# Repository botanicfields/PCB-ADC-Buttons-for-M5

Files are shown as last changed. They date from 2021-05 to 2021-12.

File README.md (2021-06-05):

# PCB-ADC-Button-for-M5
a PCB converts 5 buttons into 1 analog output

# M5 用光センサ・押しボタン 5 基板
## Ambient Light Sensor and 5 Buttons for M5

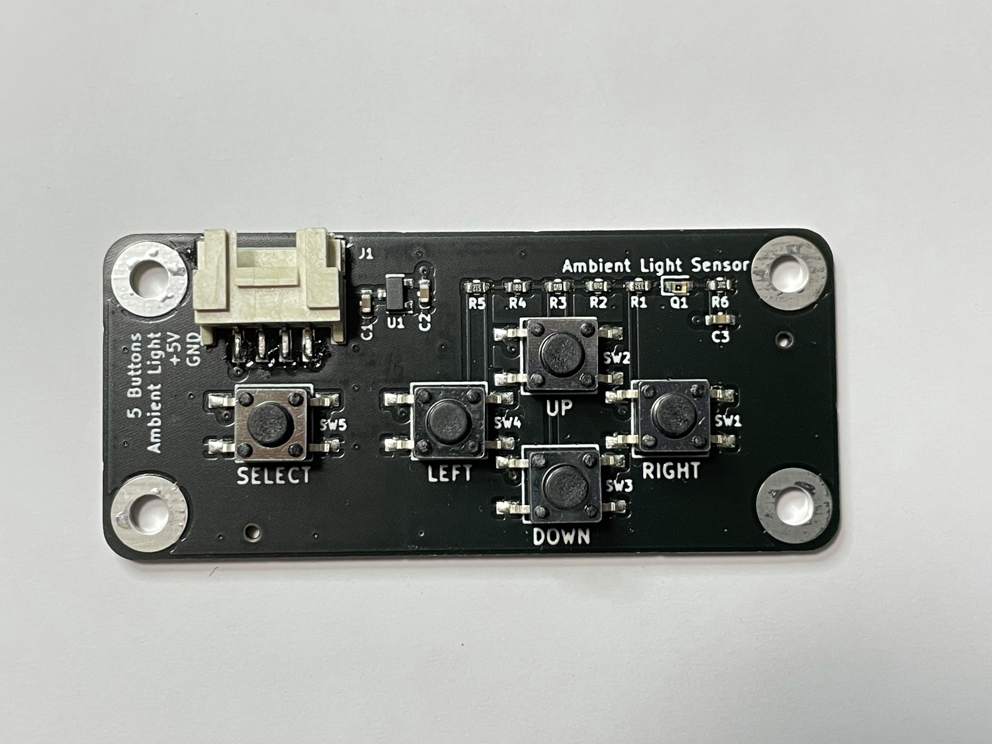
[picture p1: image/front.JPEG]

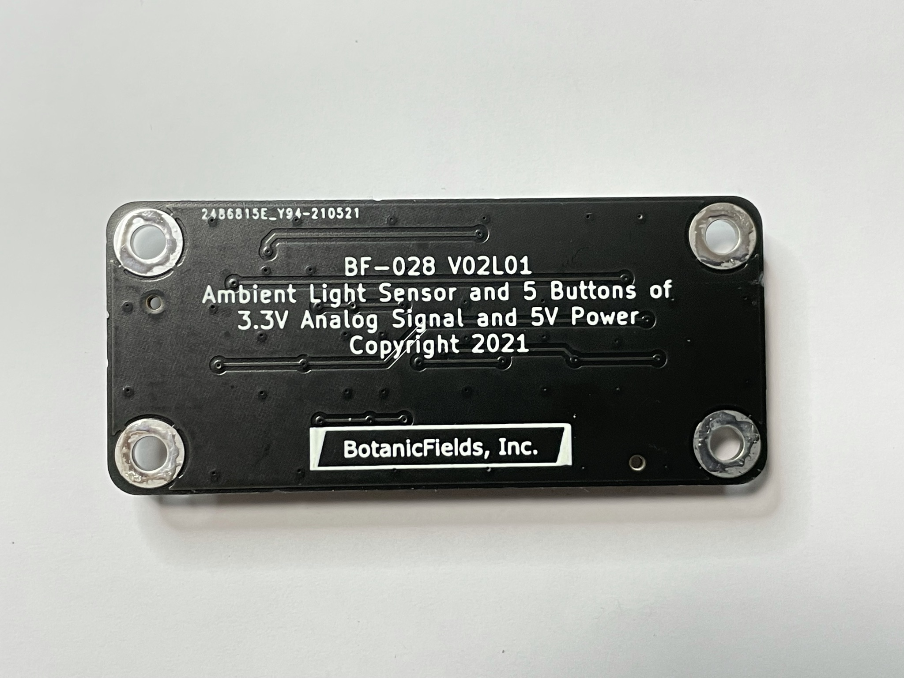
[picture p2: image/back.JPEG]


### 委託販売: スイッチサイエンス

https://www.switch-science.com/catalog/7227/

# 1. 特徴

- 周囲の明るさをアナログ電圧で出力します
- 押しボタン 5 個の操作を、1 本のアナログ電圧で出力します
- GROVE コネクタで接続します
- 出力レベルは 0 ~ 3.3V で、M5(ESP32) の GPIO に合わせています
- 電源は 5V で、M5シリーズの GROVE コネクタに合わせています
- JC_Button と同等の判定を可能とするプログラムを用意しています
- 手に持つことを考慮し、スルーホール部品を使用していません
- センサーへの影響を考慮し、パイロットランプはありません。

# 2. 注意
- 押しボタンスイッチのチャタリングや接触抵抗による誤動作が皆無とは言えません。時刻の設定など、結果を確認しながら操作し、やり直しを可能とするなど、運用でカバーできる範囲でご利用ください。

- 複数ボタンの同時押しの判定はできません。

- M5Stack Basic の GROVE コネクタに直結して使用することはできません。
「GROVE-ジャンパケーブル」などを用いて、アナログ入力の GPIO および 5V, GND に接続する必要があります。

「GROVE - 4ピン - ジャンパオスケーブル（5本セット）」

https://www.switch-science.com/catalog/6245/)

「GROVE - 4ピン-ジャンパメスケーブル (5本セット)」

https://www.switch-science.com/catalog/1048/

M5Stack Basic で、G35, G36, 5V, GND に接続した例

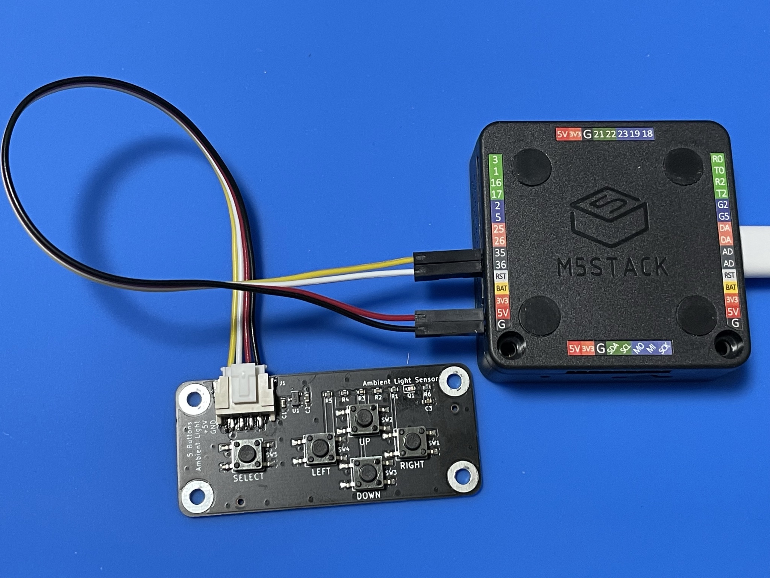
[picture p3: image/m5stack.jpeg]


## M5 シリーズの GROVE ポート

　M5 シリーズ (ESP32) では、アナログ入力として一般に G32 ～ G39 が使用されます。
G2, G4, G12 ~ G15, G24 ~ G26 のアナログ入力機能は、Wi-Fi 等が使用しますので
一般には使いづらいです。G0 はプルアップがあるなどアナログ入力には向きません。

| モデル | GROVE | 主な用途 |
|:-:|:-:|:-:|
| M5Stack Basic| G22, G21 | I2C |
| M5Stack Core2| G33, G32 | I2C, I/O, UART |
| M5StickC | G33, G32 | I2C, I/O, UART |
| M5Atom | G32, G26 | I2C, I/O, UART |

# 3. 内容

## 光センサ
Everlight ALS-PT19

https://jp.everlight.com/wp-content/plugins/ItemRelationship/product_files/pdf/ALS-PT19-315C-L177-TR8_V8.pdf

## ソフトウェア

### (1) BF_AdcButton.h, BF_Adc_Button.cpp
光センサの出力を読み出すプログラム、および 5 個の押しボタンの状態を読み出すプログラムです。JC_Button を流用・改変しています。

https://github.com/JChristensen/JC_Button

### (2) BF_AdcButtonTest.h, BF_Adc_ButtonTest.cpp
上記コードを呼び出すテスト用のプログラムです。

### (3) BF-028.ino
上記テストプログラムのメインプログラムです。

# 4. 解説
Qiita 「ESP32 のアナログ入力で、押しボタン 5 個を判別する」

https://qiita.com/BotanicFields/items/15d8d45836a4d2f6c87a

# 5. 接続例
「RGB LED 276 for M5Atom」への接続例です。

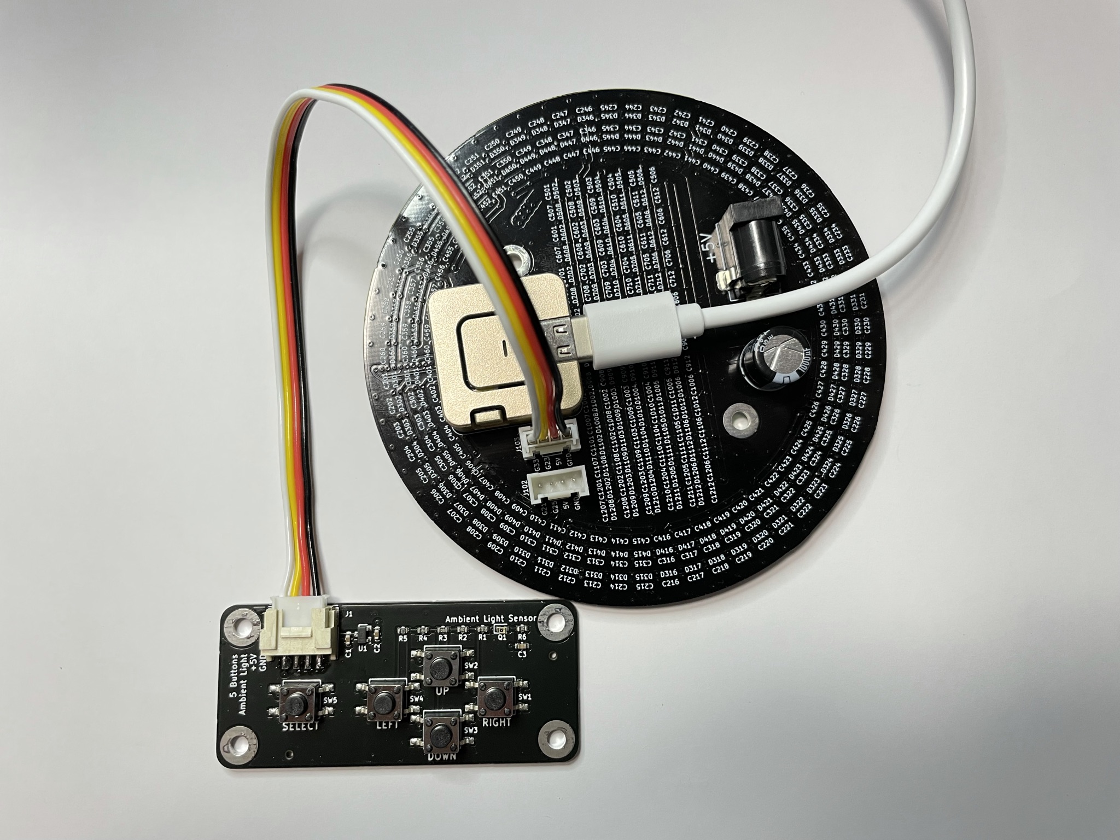
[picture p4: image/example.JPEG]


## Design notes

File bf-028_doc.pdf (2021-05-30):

BF-028 V01

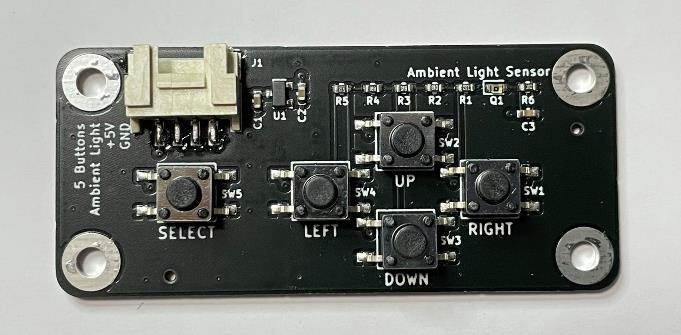
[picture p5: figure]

Copyright 2021 BotanicFields, Inc. 1

## M5 用光センサ・押しボタン 5 基板

光センサと、押しボタン 5 個を搭載した基板です。フルスケール 3.3V のアナログ信号 2 本を出力します。 M5 シリーズの GROVE コネクタ仕様に合わせ、5V の電源で動作します。

1. 内容物（各１）
(1) プリント基板
(2) GROVE 互換ケーブル 20cm
(3) 説明書（本書）
2. ご使用方法
(1) アナログ信号の取り込み
光センサ、押しボタンの各々の出力をアナログ信号として取り込む必要があります。M5 シリーズのコ ントローラ ESP32 ではアナログ入力が可能な GPIO が限られています。必ずしも GROVE コネクタ で直結できるわけではありませんのでご注意ください。
(2) ソフトウェア
「3. 参考情報」の GitHub のサンプルプログラムをご参照ください。プログラムの解説は Qiita にあり ます。
3. ご注意
(1) 基板むき出しであり、配線に触ると誤動作します。
(2) 複数ボタンの同時押しの判定はできません。
(3) 押しボタンスイッチのチャタリングや接触抵抗による誤動作が皆無とは言えません。時刻の設定など、 結果を確認しながら操作し、やり直しを可能とするなど、運用でカバーできる範囲でご利用ください。
(4) 本製品の誤動作やご利用上のトラブル等への補償はいたしません
4. 参考情報
(1) GitHub 「botanicfields/PCB-ADC-Buttons-for-M5」 https://github.com/botanicfields/PCB-ADC-Buttons-for-M5
(2) Qiita 「ESP32 のアナログ入力で、押しボタン 5 個を判別する」 https://qiita.com/BotanicFields/items/15d8d45836a4d2f6c87a

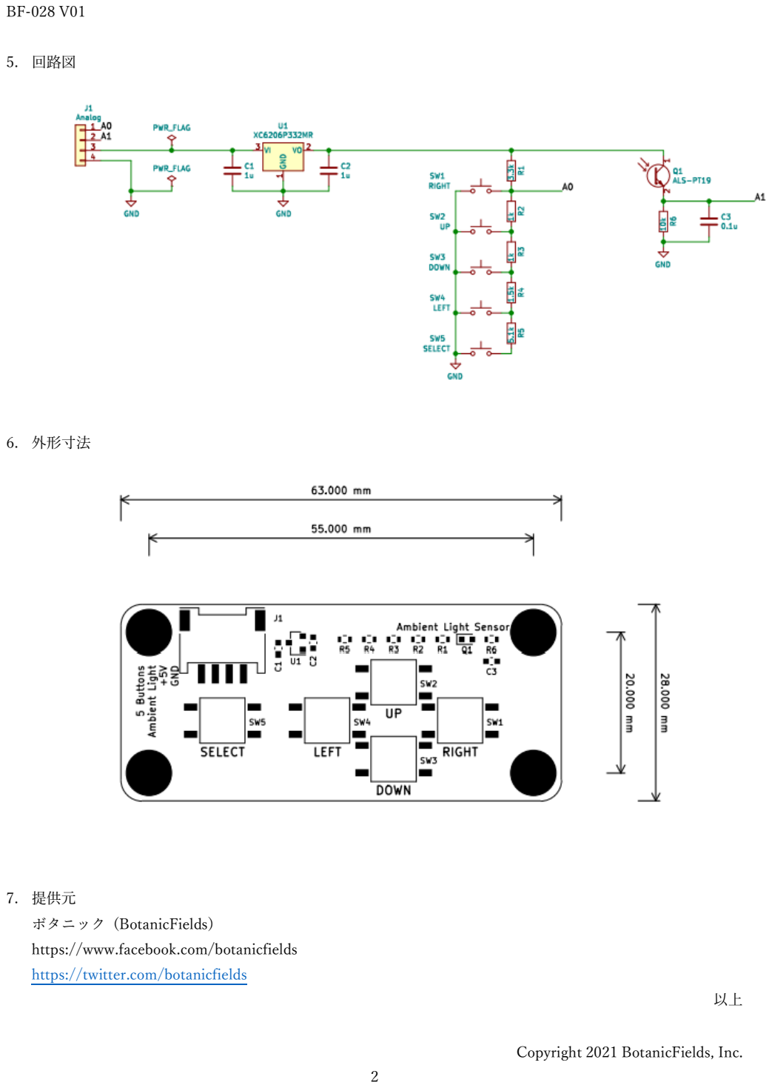
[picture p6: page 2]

BF-028 V01

Copyright 2021 BotanicFields, Inc. 2

5. 回路図
6. 外形寸法
7. 提供元
ボタニック (BotanicFields)
https://www.facebook.com/botanicfieldshttps://twitter.com/botanicfields
以上

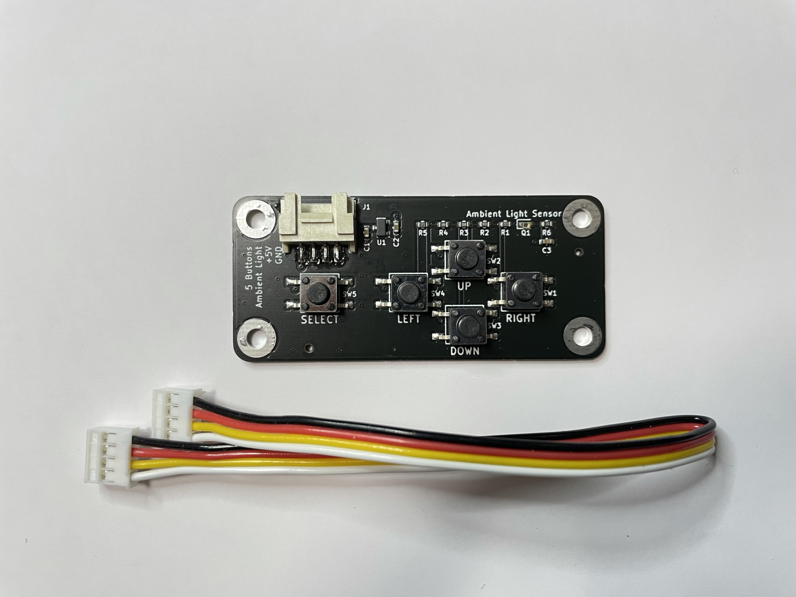
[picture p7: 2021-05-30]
image/contents.JPEG

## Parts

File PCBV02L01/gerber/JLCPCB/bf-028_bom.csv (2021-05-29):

Comment | Designator | Footprint | LCSC
1u | C1,C2 | bf:BF_C_0603_1608Metric | C15849
0.1u | C3 | bf:BF_C_0603_1608Metric | C14663
Analog | J1 | OPL_Connector:HW4-SMD-2.0-90D
ALS-PT19 | Q1 | bf:BF@ALS-PT19_0603_1608Metric | C146233
3.3k | R1 | bf:BF_R_0603_1608Metric | C22978
1k | R2,R3 | bf:BF_R_0603_1608Metric | C21190
1.5k | R4 | bf:BF_R_0603_1608Metric | C22843
5.1k | R5 | bf:BF_R_0603_1608Metric | C23186
10k | R6 | bf:BF_R_0603_1608Metric | C25804
RIGHT | SW1 | bf:BF@K2-6639SP | C83206
UP | SW2 | bf:BF@K2-6639SP | C83206
DOWN | SW3 | bf:BF@K2-6639SP | C83206
LEFT | SW4 | bf:BF@K2-6639SP | C83206
SELECT | SW5 | bf:BF@K2-6639SP | C83206
XC6206P332MR | U1 | Package_TO_SOT_SMD:SOT-23 | C5446

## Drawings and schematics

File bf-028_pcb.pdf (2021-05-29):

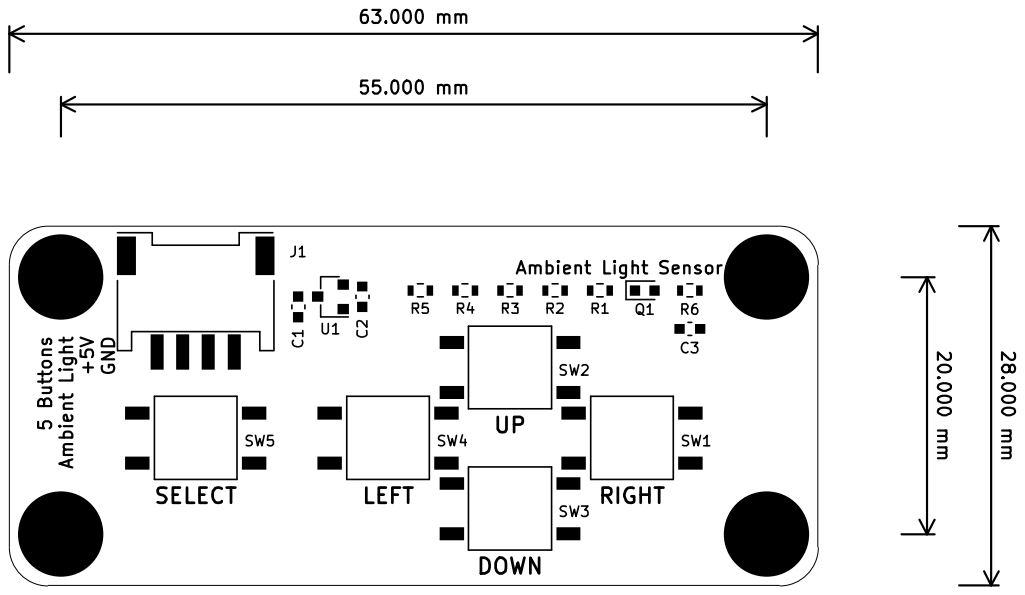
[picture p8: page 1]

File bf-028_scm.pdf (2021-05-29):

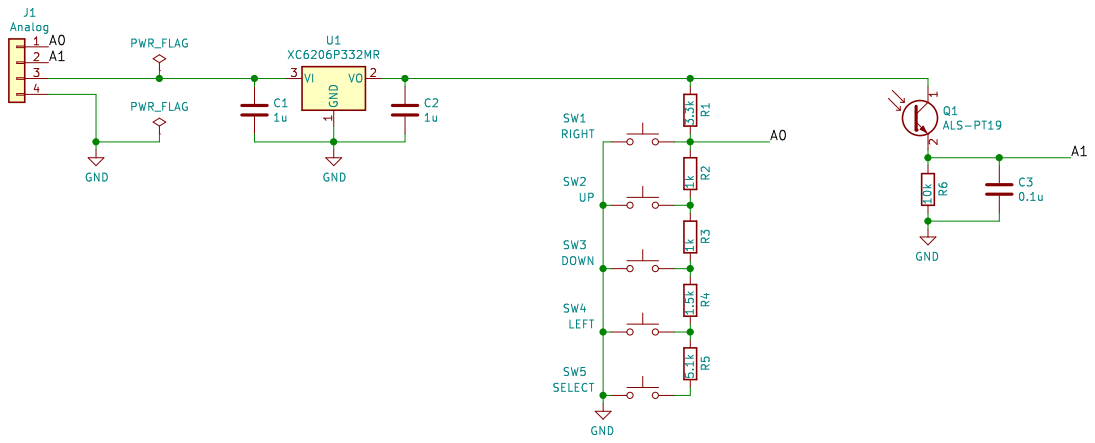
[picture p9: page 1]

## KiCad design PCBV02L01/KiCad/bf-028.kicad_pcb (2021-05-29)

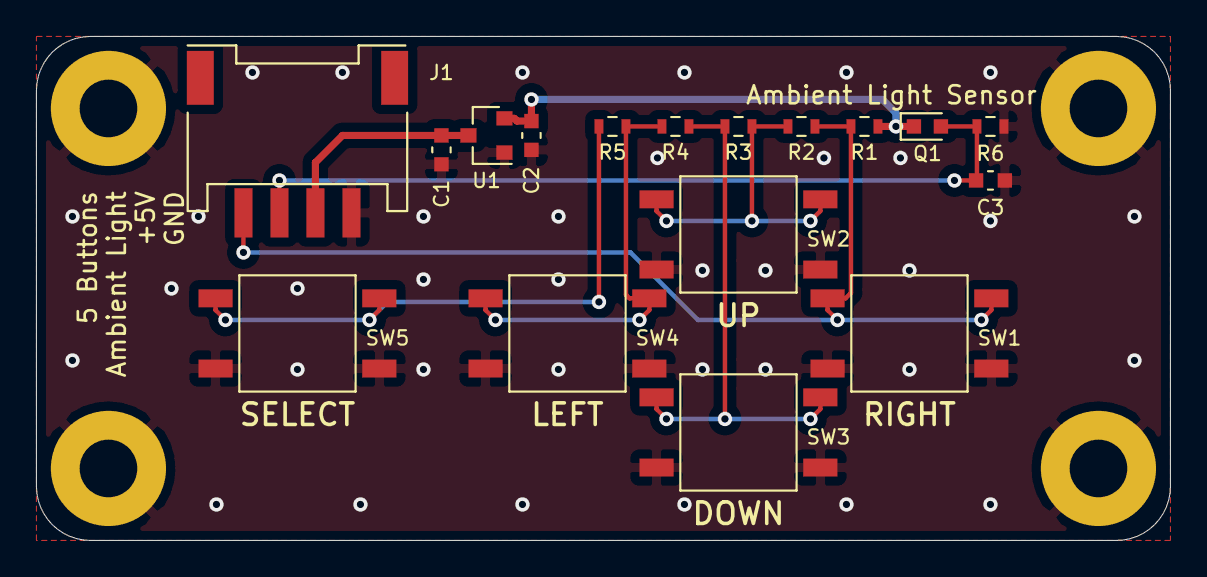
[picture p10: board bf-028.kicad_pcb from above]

Board: 2 copper layers, 63.0 x 28.0 mm, 17 parts (0 on the bottom side), 9 nets.

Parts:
C1, C2: 1u; BF_C_0603_1608Metric
C3: 0.1u; BF_C_0603_1608Metric
J1: Analog; HW4-SMD-2.0-90D
Q1: ALS-PT19; BF@ALS-PT19_0603_1608Metric
R1: 3.3k; BF_R_0603_1608Metric
R2, R3: 1k; BF_R_0603_1608Metric
R4: 1.5k; BF_R_0603_1608Metric
R5: 5.1k; BF_R_0603_1608Metric
R6: 10k; BF_R_0603_1608Metric
SW1: RIGHT; BF@K2-6639SP
SW2: UP; BF@K2-6639SP
SW3: DOWN; BF@K2-6639SP
SW4: LEFT; BF@K2-6639SP
SW5: SELECT; BF@K2-6639SP
U1: XC6206P332MR; SOT-23

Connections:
/A0: J1.1, R1.2, R2.1, SW1.1
/A1: C3.1, J1.2, Q1.2, R6.1
GND: C1.2, C2.2, C3.2, J1.4, R6.2, SW1.2, SW2.2, SW3.2, SW4.2, SW5.2, U1.1
unnamed: C1.1, J1.3, U1.3
unnamed: C2.1, Q1.1, R1.1, U1.2
unnamed: R2.2, R3.1, SW2.1
unnamed: R3.2, R4.1, SW3.1
unnamed: R4.2, R5.1, SW4.1
unnamed: R5.2, SW5.1

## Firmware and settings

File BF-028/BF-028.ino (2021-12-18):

// Copyright 2021 BotanicFields, Inc.
// BF-028: Ambient Light Sensor and 5 Buttons of 3.3V Analog Signal and 5V Power
// test and example

//#define M5STACK
//#define M5STICKC
//#define M5STICKCPLUS
#define M5ATOM

#ifdef M5STACK
#include <M5Stack.h>
#endif
#ifdef M5STICKC
#include <M5StickC.h>
#endif
#ifdef M5STICKCPLUS
#include <M5StickCPlus.h>
#endif
#ifdef M5ATOM
#include <M5Atom.h>
#endif

#include "BF_AdcButton.h"
#include "BF_AdcButtonTest.h"

// loop contol
const int ambient_period_ms(1000);  // 5sec
const int loop_delay_ms(20);
unsigned int last_ms(0);
int loop_count(0);

void setup()
{
#ifdef M5STACK
  const bool lcd_enable(true);
  const bool sd_enable(true);
  const bool serial_enable(true);
  const bool i2c_enable(true);
  M5.begin(lcd_enable, sd_enable, serial_enable, i2c_enable);
  const int analog_port_button_pin(35);  // GPIO35 <NOT GROVE-A PORT> 
  const int ambient_light_pin(36);       // GPIO36 <NOT GROVE-A PORT>
#endif
#ifdef M5STICKC
  const bool lcd_enable(true);
  const bool power_enable(true);
  const bool serial_enable(true);
  M5.begin(lcd_enable, power_enable, serial_enable);
  const int analog_port_button_pin(33);  // GPIO33
  const int ambient_light_pin(32);       // GPIO32
#endif
#ifdef M5STICKCPLUS
  const bool lcd_enable(true);
  const bool power_enable(true);
  const bool serial_enable(true);
  M5.begin(lcd_enable, power_enable, serial_enable);
  const int analog_port_button_pin(33);  // GPIO33
  const int ambient_light_pin(32);       // GPIO32
#endif
#ifdef M5ATOM
  const bool serial_enable(true);
  const bool i2c_enable(true);
  const bool display_enable(true);
  M5.begin(serial_enable, i2c_enable, display_enable);
  const int analog_port_button_pin(32);  // GPIO32
  const int ambient_light_pin(26);       // GPIO26 <Wi-Fi CANNOT BE USED>
#endif

  AdcButtonBegin(analog_port_button_pin);
  ambient_light_sensor.Begin(ambient_light_pin);

  loop_count = 0;
  last_ms = millis();
}

void loop()
{
  M5.update();
  AdcButtonUpdate();

  if (loop_count % (ambient_period_ms / loop_delay_ms) == 0) {
    int ambient_light = ambient_light_sensor.Read();
    Serial.printf("Ambient light sensor = %d\n", ambient_light);
  }

//  TestisPressed();
//  TestisReleased(0);
//  TestisReleased(1);
//  TestisReleased(2);
//  TestisReleased(3);
//  TestisReleased(4);
  TestwasPressed();
  TestwasReleased();
  TestpressedFor(1000);
//  TestreleasedFor(0, 3000);
//  TestreleasedFor(1, 3000);
//  TestreleasedFor(2, 3000);
//  TestreleasedFor(3, 3000);
//  TestreleasedFor(4, 3000);

  ++loop_count;
  delay(last_ms + loop_delay_ms - millis());
  last_ms = millis();
}

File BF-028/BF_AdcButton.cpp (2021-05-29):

// Copyright 2021 BotanicFields, Inc.
// BF-028: Ambient Light Sensor and 5 Buttons of 3.3V Analog Signal and 5V Power 
//
// - Modification of JC_Button https://github.com/JChristensen/JC_Button
// - class Button --> class AdcButton
// - class ToggleButton --> not supported
// GNU GPL v3.0, https://www.gnu.org/licenses/gpl.html
//
// class AdcButtonPort
//   Analog Digital Converter Port for 5 Buttons
// class ADCButton
//   buttons connected to the AdcButtonPort, can be used as the JC_Button
// instances
//   Begin and Update collectively, instead of individual read of AdcButton

#include "BF_AdcButton.h"

//..:....1....:....2....:....3....:....4....:....5....:....6....:....7....:....8
void AdcButtonPort::Begin(int adc_pin)
{
  m_adc_pin = adc_pin;
}

void AdcButtonPort::Update()
{
  m_adc_read = analogRead(m_adc_pin);
//  AdcReadStable();  // use this instead of the line above to check the stability of analog read
//  AdcStatistics();  // for statistical analysis of analog reads
}

// The argument button specifies the button number instead of the GPIO number.
// Returns false when the button is pressed to be consistent with digitalRead().
//   button   Resistor    voltage ratio      95%    mV  105%   95%   ADC  105%       experimental
//   0  Right      0     0 /  3300 = 0               0..   0           0..   0 -->          0.. 200
//   1  Up      1000  1000 /  4300 = 0.233   729.. 767.. 806   905.. 952..1000      700.. 820..1100
//   2  Down    1000  2000 /  5300 = 0.377  1183..1245..1308  1468..1545..1623 --> 1300..1430..1700
//   3  Left    1500  3500 /  6800 = 0.515  1614..1699..1783  2002..2108..2213 --> 1900..2000..2300
//   4  Select  5100  8600 / 11900 = 0.723  2266..2385..2504  2811..2959..3107 --> 2700..2870..3100
//   -    -     3300                 1.0    3135..3300        3890..4095
bool AdcButtonPort::DigitalRead(int button)
{
  switch (button) {
    case 0: if (                     m_adc_read <  200) return false;  break;
    case 1: if (m_adc_read >  700 && m_adc_read < 1100) return false;  break;
    case 2: if (m_adc_read > 1300 && m_adc_read < 1700) return false;  break;
    case 3: if (m_adc_read > 1900 && m_adc_read < 2300) return false;  break;
    case 4: if (m_adc_read > 2700 && m_adc_read < 3100) return false;  break;
    default: break;
  }
  return true;
}

void AdcButtonPort::AdcReadStable()
{
  const int stable_range(50);    // range to judge stable
  const int loop_count_max(10);  // timeout to judge stable

  int adc_read1(m_adc_read_max);
  int loop_count(0);
  int adc_read_history[loop_count_max];
  while (true) {
    int adc_read2 = analogRead(m_adc_pin);
    adc_read_history[loop_count] = adc_read2;
    if (abs(adc_read1 - adc_read2) < stable_range)
      break;
    adc_read1 = adc_read2;

    if (++loop_count >= loop_count_max) {
      adc_read1 = m_adc_read_max;
      Serial.println("[ADC Read] Times over for stable");
      break;
    }
  }
  m_adc_read = adc_read1;

  if (m_adc_read != m_adc_read_max) {
    Serial.printf("[ADC Read] loop_count= %d: ", loop_count);
    for (int i = 0; i <= loop_count; ++i)
      Serial.printf("%d, ", adc_read_history[i]);
    Serial.printf("m_adc_read= %d\n", m_adc_read);
  }
}

void AdcButtonPort::AdcStatistics()
{
  const int     show_period(100);  // 100 times
  static int    adc_count(0);
  static int    adc_max(0);
  static int    adc_min(m_adc_read_max);
  static double adc_sum(0.0);
  static double adc_sq_sum(0.0);

  if (m_adc_read < m_adc_read_max) {
    ++adc_count;
    if (adc_max < m_adc_read) adc_max = m_adc_read;
    if (adc_min > m_adc_read) adc_min = m_adc_read;
    adc_sum += (double)m_adc_read;
    adc_sq_sum += (double)m_adc_read * (double)m_adc_read;

    if (adc_count % show_period == 0) {
      double adc_average = adc_sum / (double)adc_count;
      double adc_variance = (adc_sq_sum - adc_sum * adc_sum / (double)adc_count) / (double)adc_count;
      double adc_std_deviation = sqrt(adc_variance);
      Serial.printf("[ADC Read] n= %d, ave= %.4f  sdv= %.4f  min= %d  max= %d\n",
                    adc_count, adc_average, adc_std_deviation, adc_min, adc_max);
    }
  }
}

//..:....1....:....2....:....3....:....4....:....5....:....6....:....7....:....8
// Arduino Button Library
// https://github.com/JChristensen/JC_Button
// Copyright (C) 2018 by Jack Christensen and licensed under
// GNU GPL v3.0, https://www.gnu.org/licenses/gpl.html

//[Adc]#include "JC_Button.h"

/*----------------------------------------------------------------------*
/ initialize a Button object and the pin it's connected to.             *
/-----------------------------------------------------------------------*/
//[Adc]void Button::begin()
void AdcButton::begin(AdcButtonPort* adc_btn)
{
    m_adc_btn = adc_btn;
//[Adc]    pinMode(m_pin, m_puEnable ? INPUT_PULLUP : INPUT);
//[Adc]    m_state = digitalRead(m_pin);
    m_state = m_adc_btn->DigitalRead(m_pin);
    if (m_invert) m_state = !m_state;
    m_time = millis();
    m_lastState = m_state;
    m_changed = false;
    m_lastChange = m_time;
}

/*----------------------------------------------------------------------*
/ returns the state of the button, true if pressed, false if released.  *
/ does debouncing, captures and maintains times, previous state, etc.   *
/-----------------------------------------------------------------------*/
//[Adc]bool Button::read()
bool AdcButton::read()
{
    uint32_t ms = millis();
//[Adc]    bool pinVal = digitalRead(m_pin);
    bool pinVal = m_adc_btn->DigitalRead(m_pin);
    if (m_invert) pinVal = !pinVal;
    if (ms - m_lastChange < m_dbTime)
    {
        m_changed = false;
    }
    else
    {
        m_lastState = m_state;
        m_state = pinVal;
        m_changed = (m_state != m_lastState);
        if (m_changed) m_lastChange = ms;
    }
    m_time = ms;
    return m_state;
}

/*----------------------------------------------------------------------*
 * isPressed() and isReleased() check the button state when it was last *
 * read, and return false (0) or true (!=0) accordingly.                *
 * These functions do not cause the button to be read.                  *
 *----------------------------------------------------------------------*/
//[Adc]bool Button::isPressed()
bool AdcButton::isPressed()
{
    return m_state;
}

//[Adc]bool Button::isReleased()
bool AdcButton::isReleased()
{
    return !m_state;
}

/*----------------------------------------------------------------------*
 * wasPressed() and wasReleased() check the button state to see if it   *
 * changed between the last two reads and return false (0) or           *
 * true (!=0) accordingly.                                              *
 * These functions do not cause the button to be read.                  *
 *----------------------------------------------------------------------*/
//[Adc]bool Button::wasPressed()
bool AdcButton::wasPressed()
{
    return m_state && m_changed;
}
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

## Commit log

2021-05-29 first revision
    [bf-028.kicad_pcb, bf-028.sch, bf-028_bom.csv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]
2021-05-30 add doc
    move pdf to root
    [simulation.xlsx]
2021-06-04 Update README.md
    add Switch Science Market Place
